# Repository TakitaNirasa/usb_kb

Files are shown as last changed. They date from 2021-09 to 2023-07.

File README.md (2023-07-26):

# Двухкнопочная клавиатура

[Проект печатной платы](https://github.com/TakitaNirasa/usb_kb/tree/main/sch_pcb)

[3D модели](https://github.com/TakitaNirasa/usb_kb/tree/main/3d_models%26drawings)

[Код](https://github.com/TakitaNirasa/usb_kb/tree/main/code/usb_kb_103)

[Схема](https://github.com/TakitaNirasa/usb_kb/tree/main/sch_pcb/usb_kb.pdf)

Для сборки проекта:
1. Перейти в директорию code/usb_kb_103/Debug
2. Собрать проект командой make all (Для сборки требуются пакеты: make, stlink-tools, binutils-arm-none-eabi)
3. Подключить плату к программатору (см. схему) и запитать её по usb кабелю
4. Ввести команду ./load_stm32

Скрин 3d модели корпуса для красоты:  

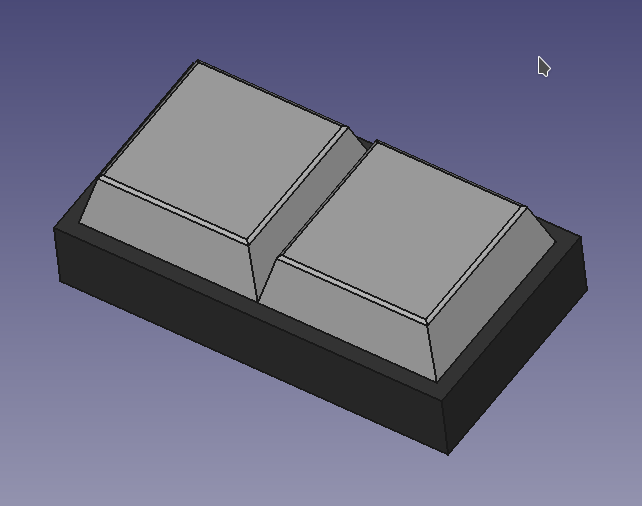
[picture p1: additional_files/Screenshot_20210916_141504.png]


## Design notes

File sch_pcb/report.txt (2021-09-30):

Информация: Обработка компонента "J1:/615DD6C5:Connector_PinHeader_2.54mm:PinHeader_1x04_P2.54mm_Vertical".
Информация: Обработка компонента "C14:/61573A60:Capacitor_SMD:C_0805_2012Metric_Pad1.15x1.40mm_HandSolder".
Информация: Обработка компонента "R14:/616A5D0F:Resistor_SMD:R_0603_1608Metric_Pad1.05x0.95mm_HandSolder".
Информация: Обработка компонента "C15:/61594438:Capacitor_SMD:C_0805_2012Metric_Pad1.15x1.40mm_HandSolder".
Информация: Обработка компонента "R13:/615C8D27:Resistor_SMD:R_0603_1608Metric_Pad1.05x0.95mm_HandSolder".
Информация: Обработка компонента "D1:/615BE243:Diode_SMD:D_SMA".
Информация: Обработка компонента "R12:/61584F00:Resistor_SMD:R_0603_1608Metric_Pad1.05x0.95mm_HandSolder".
Информация: Обработка компонента "D2:/6157EF82:Diode_SMD:D_0805_2012Metric_Pad1.15x1.40mm_HandSolder".
Информация: Обработка компонента "R11:/61567374:Resistor_SMD:R_0603_1608Metric_Pad1.05x0.95mm_HandSolder".
Информация: Обработка компонента "D3:/615BC87B:Diode_SMD:D_0805_2012Metric_Pad1.15x1.40mm_HandSolder".
Информация: Обработка компонента "R10:/61563424:Resistor_SMD:R_0603_1608Metric_Pad1.05x0.95mm_HandSolder".
Информация: Обработка компонента "D4:/615B3C03:Diode_SMD:D_0805_2012Metric_Pad1.15x1.40mm_HandSolder".
Информация: Обработка компонента "R9:/615BC881:Resistor_SMD:R_0603_1608Metric_Pad1.05x0.95mm_HandSolder".
Информация: Обработка компонента "R15:/616A4701:Resistor_SMD:R_0603_1608Metric_Pad1.05x0.95mm_HandSolder".
Информация: Обработка компонента "R8:/615B3C09:Resistor_SMD:R_0603_1608Metric_Pad1.05x0.95mm_HandSolder".
Информация: Обработка компонента "JP1:/615515A1:Jumper:SolderJumper-2_P1.3mm_Open_TrianglePad1.0x1.5mm".
Информация: Обработка компонента "R7:/615819F2:Resistor_SMD:R_0603_1608Metric_Pad1.05x0.95mm_HandSolder".
Информация: Обработка компонента "JP2:/61571C30:Jumper:SolderJumper-2_P1.3mm_Open_TrianglePad1.0x1.5mm".
Информация: Обработка компонента "R6:/6176BF06:Resistor_SMD:R_0603_1608Metric_Pad1.05x0.95mm_HandSolder".
Информация: Обработка компонента "P1:/6152BA8E:Connector_USB:USB_C_Receptacle_HRO_TYPE-C-31-M-12".
Информация: Обработка компонента "R5:/61687768:Resistor_SMD:R_0603_1608Metric_Pad1.05x0.95mm_HandSolder".
Информация: Обработка компонента "R1:/6155C064:Resistor_SMD:R_0603_1608Metric_Pad1.05x0.95mm_HandSolder".
Информация: Обработка компонента "R4:/615A1C71:Resistor_SMD:R_0603_1608Metric_Pad1.05x0.95mm_HandSolder".
Информация: Обработка компонента "R2:/6155F9D5:Resistor_SMD:R_0603_1608Metric_Pad1.05x0.95mm_HandSolder".
Информация: Обработка компонента "R3:/6163586F:Resistor_SMD:R_0603_1608Metric_Pad1.05x0.95mm_HandSolder".
Информация: Обработка компонента "C13:/616EB914:Capacitor_SMD:C_0805_2012Metric_Pad1.15x1.40mm_HandSolder".
Информация: Обработка компонента "C1:/6159B622:Capacitor_SMD:C_0805_2012Metric_Pad1.15x1.40mm_HandSolder".
Информация: Обработка компонента "C2:/61570A54:Capacitor_SMD:C_0805_2012Metric_Pad1.15x1.40mm_HandSolder".
Информация: Обработка компонента "X1:/615A0FA7:Crystal:Crystal_HC49-4H_Vertical".
Информация: Обработка компонента "C3:/615A45ED:Capacitor_SMD:C_0805_2012Metric_Pad1.15x1.40mm_HandSolder".
Информация: Обработка компонента "C4:/615A45E7:Capacitor_SMD:C_0805_2012Metric_Pad1.15x1.40mm_HandSolder".
Информация: Обработка компонента "U3:/615B256A:Package_TO_SOT_SMD:SOT-223-3_TabPin2".
Информация: Обработка компонента "C5:/61610E10:Capacitor_SMD:C_0805_2012Metric_Pad1.15x1.40mm_HandSolder".
Информация: Обработка компонента "C6:/61612EA3:Capacitor_SMD:C_0805_2012Metric_Pad1.15x1.40mm_HandSolder".
Информация: Обработка компонента "U2:/61609EAF:Package_TO_SOT_SMD:SOT-23-6".
Информация: Обработка компонента "C7:/61613FDA:Capacitor_SMD:C_0805_2012Metric_Pad1.15x1.40mm_HandSolder".
Информация: Обработка компонента "C8:/616148F3:Capacitor_SMD:C_0805_2012Metric_Pad1.15x1.40mm_HandSolder".
Информация: Обработка компонента "U1:/6153426E:Package_QFP:LQFP-48_7x7mm_P0.5mm".
Информация: Обработка компонента "C9:/615BF44D:Capacitor_SMD:C_0805_2012Metric_Pad1.15x1.40mm_HandSolder".
Информация: Обработка компонента "C10:/615BE780:Capacitor_SMD:C_0805_2012Metric_Pad1.15x1.40mm_HandSolder".
Информация: Обработка компонента "SW2:/615AD94E:Button_Switch_Keyboard:SW_Cherry_MX_1.00u_PCB".
Информация: Обработка компонента "C11:/61631C3A:Capacitor_SMD:C_0805_2012Metric_Pad1.15x1.40mm_HandSolder".
Информация: Обработка компонента "C12:/616EB91A:Capacitor_SMD:C_0805_2012Metric_Pad1.15x1.40mm_HandSolder".
Информация: Обработка компонента "SW1:/6155A06F:Button_Switch_Keyboard:SW_Cherry_MX_1.00u_PCB".
Добавлено U1 (посад.место "Package_QFP:LQFP-48_7x7mm_P0.5mm").
Добавлено SW2 (посад.место "Button_Switch_Keyboard:SW_Cherry_MX_1.00u_PCB").
Добавлено U2 (посад.место "Package_TO_SOT_SMD:SOT-23-6").
Добавлено U3 (посад.место "Package_TO_SOT_SMD:SOT-223-3_TabPin2").
Добавлено SW1 (посад.место "Button_Switch_Keyboard:SW_Cherry_MX_1.00u_PCB").
Добавлено X1 (посад.место "Crystal:Crystal_HC49-4H_Vertical").
Добавлено P1 (посад.место "Connector_USB:USB_C_Receptacle_HRO_TYPE-C-31-M-12").
Добавлено JP2 (посад.место "Jumper:SolderJumper-2_P1.3mm_Open_TrianglePad1.0x1.5mm").
Добавлено D1 (посад.место "Diode_SMD:D_SMA").
Добавлено JP1 (посад.место "Jumper:SolderJumper-2_P1.3mm_Open_TrianglePad1.0x1.5mm").
Добавлено J1 (посад.место "Connector_PinHeader_2.54mm:PinHeader_1x04_P2.54mm_Vertical").
Добавлено D2 (посад.место "Diode_SMD:D_0805_2012Metric_Pad1.15x1.40mm_HandSolder").
Добавлено D4 (посад.место "Diode_SMD:D_0805_2012Metric_Pad1.15x1.40mm_HandSolder").
Добавлено D3 (посад.место "Diode_SMD:D_0805_2012Metric_Pad1.15x1.40mm_HandSolder").
Ошибка: Не удалось добавить C7 (посад.место "Capacitor_SMD:C_0805_2012Metric_Pad1.15x1.40mm_HandSolder" не найдено).
Ошибка: Не удалось добавить C13 (посад.место "Capacitor_SMD:C_0805_2012Metric_Pad1.15x1.40mm_HandSolder" не найдено).
Ошибка: Не удалось добавить R15 (посад.место "Resistor_SMD:R_0603_1608Metric_Pad1.05x0.95mm_HandSolder" не найдено).
Ошибка: Не удалось добавить C12 (посад.место "Capacitor_SMD:C_0805_2012Metric_Pad1.15x1.40mm_HandSolder" не найдено).
Ошибка: Не удалось добавить C11 (посад.место "Capacitor_SMD:C_0805_2012Metric_Pad1.15x1.40mm_HandSolder" не найдено).
Ошибка: Не удалось добавить C10 (посад.место "Capacitor_SMD:C_0805_2012Metric_Pad1.15x1.40mm_HandSolder" не найдено).
Ошибка: Не удалось добавить C9 (посад.место "Capacitor_SMD:C_0805_2012Metric_Pad1.15x1.40mm_HandSolder" не найдено).
Ошибка: Не удалось добавить C8 (посад.место "Capacitor_SMD:C_0805_2012Metric_Pad1.15x1.40mm_HandSolder" не найдено).
Ошибка: Не удалось добавить R12 (посад.место "Resistor_SMD:R_0603_1608Metric_Pad1.05x0.95mm_HandSolder" не найдено).
Ошибка: Не удалось добавить C6 (посад.место "Capacitor_SMD:C_0805_2012Metric_Pad1.15x1.40mm_HandSolder" не найдено).
Ошибка: Не удалось добавить C5 (посад.место "Capacitor_SMD:C_0805_2012Metric_Pad1.15x1.40mm_HandSolder" не найдено).
Ошибка: Не удалось добавить C4 (посад.место "Capacitor_SMD:C_0805_2012Metric_Pad1.15x1.40mm_HandSolder" не найдено).
Ошибка: Не удалось добавить C3 (посад.место "Capacitor_SMD:C_0805_2012Metric_Pad1.15x1.40mm_HandSolder" не найдено).
Ошибка: Не удалось добавить C2 (посад.место "Capacitor_SMD:C_0805_2012Metric_Pad1.15x1.40mm_HandSolder" не найдено).
Ошибка: Не удалось добавить C1 (посад.место "Capacitor_SMD:C_0805_2012Metric_Pad1.15x1.40mm_HandSolder" не найдено).
Ошибка: Не удалось добавить R14 (посад.место "Resistor_SMD:R_0603_1608Metric_Pad1.05x0.95mm_HandSolder" не найдено).
Ошибка: Не удалось добавить C14 (посад.место "Capacitor_SMD:C_0805_2012Metric_Pad1.15x1.40mm_HandSolder" не найдено).
Ошибка: Не удалось добавить R13 (посад.место "Resistor_SMD:R_0603_1608Metric_Pad1.05x0.95mm_HandSolder" не найдено).
Ошибка: Не удалось добавить C15 (посад.место "Capacitor_SMD:C_0805_2012Metric_Pad1.15x1.40mm_HandSolder" не найдено).
Ошибка: Не удалось добавить R2 (посад.место "Resistor_SMD:R_0603_1608Metric_Pad1.05x0.95mm_HandSolder" не найдено).
Ошибка: Не удалось добавить R11 (посад.место "Resistor_SMD:R_0603_1608Metric_Pad1.05x0.95mm_HandSolder" не найдено).
Ошибка: Не удалось добавить R10 (посад.место "Resistor_SMD:R_0603_1608Metric_Pad1.05x0.95mm_HandSolder" не найдено).
Ошибка: Не удалось добавить R9 (посад.место "Resistor_SMD:R_0603_1608Metric_Pad1.05x0.95mm_HandSolder" не найдено).
Ошибка: Не удалось добавить R8 (посад.место "Resistor_SMD:R_0603_1608Metric_Pad1.05x0.95mm_HandSolder" не найдено).
Ошибка: Не удалось добавить R7 (посад.место "Resistor_SMD:R_0603_1608Metric_Pad1.05x0.95mm_HandSolder" не найдено).
Ошибка: Не удалось добавить R6 (посад.место "Resistor_SMD:R_0603_1608Metric_Pad1.05x0.95mm_HandSolder" не найдено).
Ошибка: Не удалось добавить R5 (посад.место "Resistor_SMD:R_0603_1608Metric_Pad1.05x0.95mm_HandSolder" не найдено).
Ошибка: Не удалось добавить R4 (посад.место "Resistor_SMD:R_0603_1608Metric_Pad1.05x0.95mm_HandSolder" не найдено).
Ошибка: Не удалось добавить R1 (посад.место "Resistor_SMD:R_0603_1608Metric_Pad1.05x0.95mm_HandSolder" не найдено).
Ошибка: Не удалось добавить R3 (посад.место "Resistor_SMD:R_0603_1608Metric_Pad1.05x0.95mm_HandSolder" не найдено).

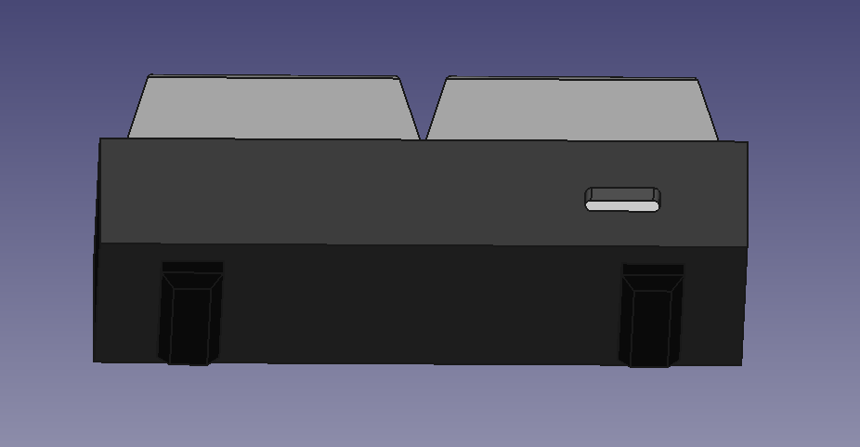
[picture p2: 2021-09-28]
additional_files/Screenshot_20210916_141544.png

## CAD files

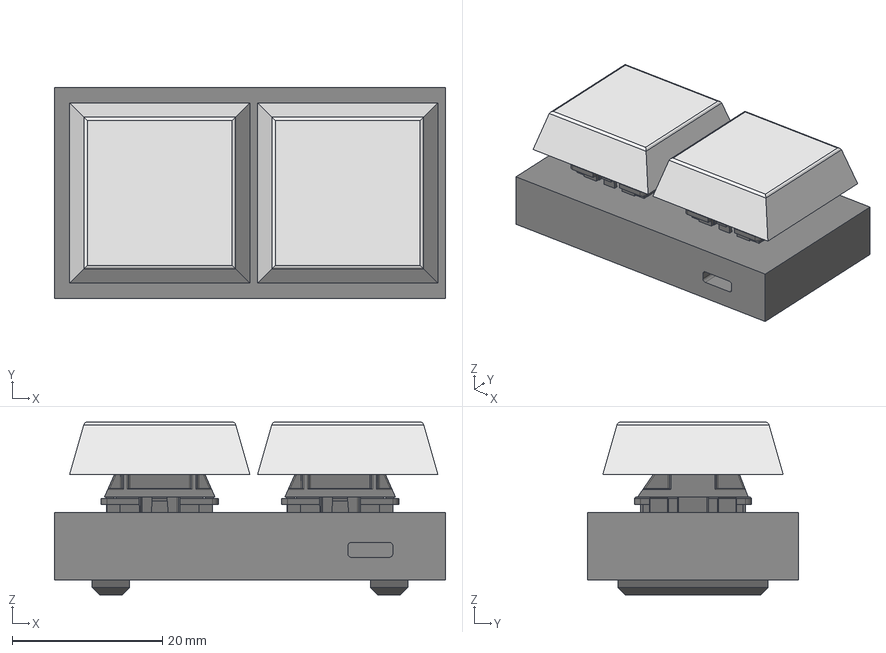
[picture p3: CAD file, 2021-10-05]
3d_models&drawings/kl1.0.FCStd
52.0 x 28.0 x 23.0 mm
BUTTON
BUTTON001
REZINKA
REZINKA001
KORP
SW_Cherry_MX_PCB_cp
SW_Cherry_MX_PCB_cp001

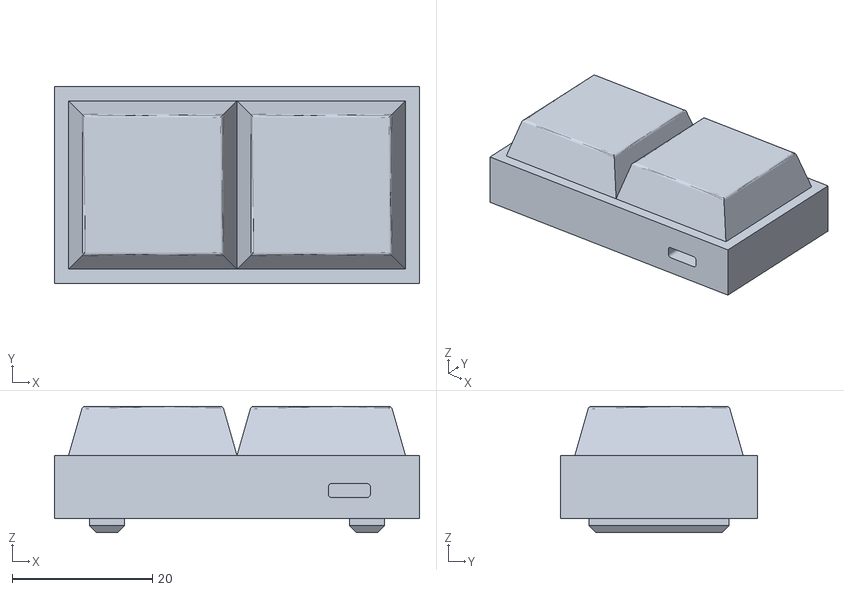
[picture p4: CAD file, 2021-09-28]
3d_models&drawings/usb_kb_sketch.stl
52.0 x 28.0 x 18.0

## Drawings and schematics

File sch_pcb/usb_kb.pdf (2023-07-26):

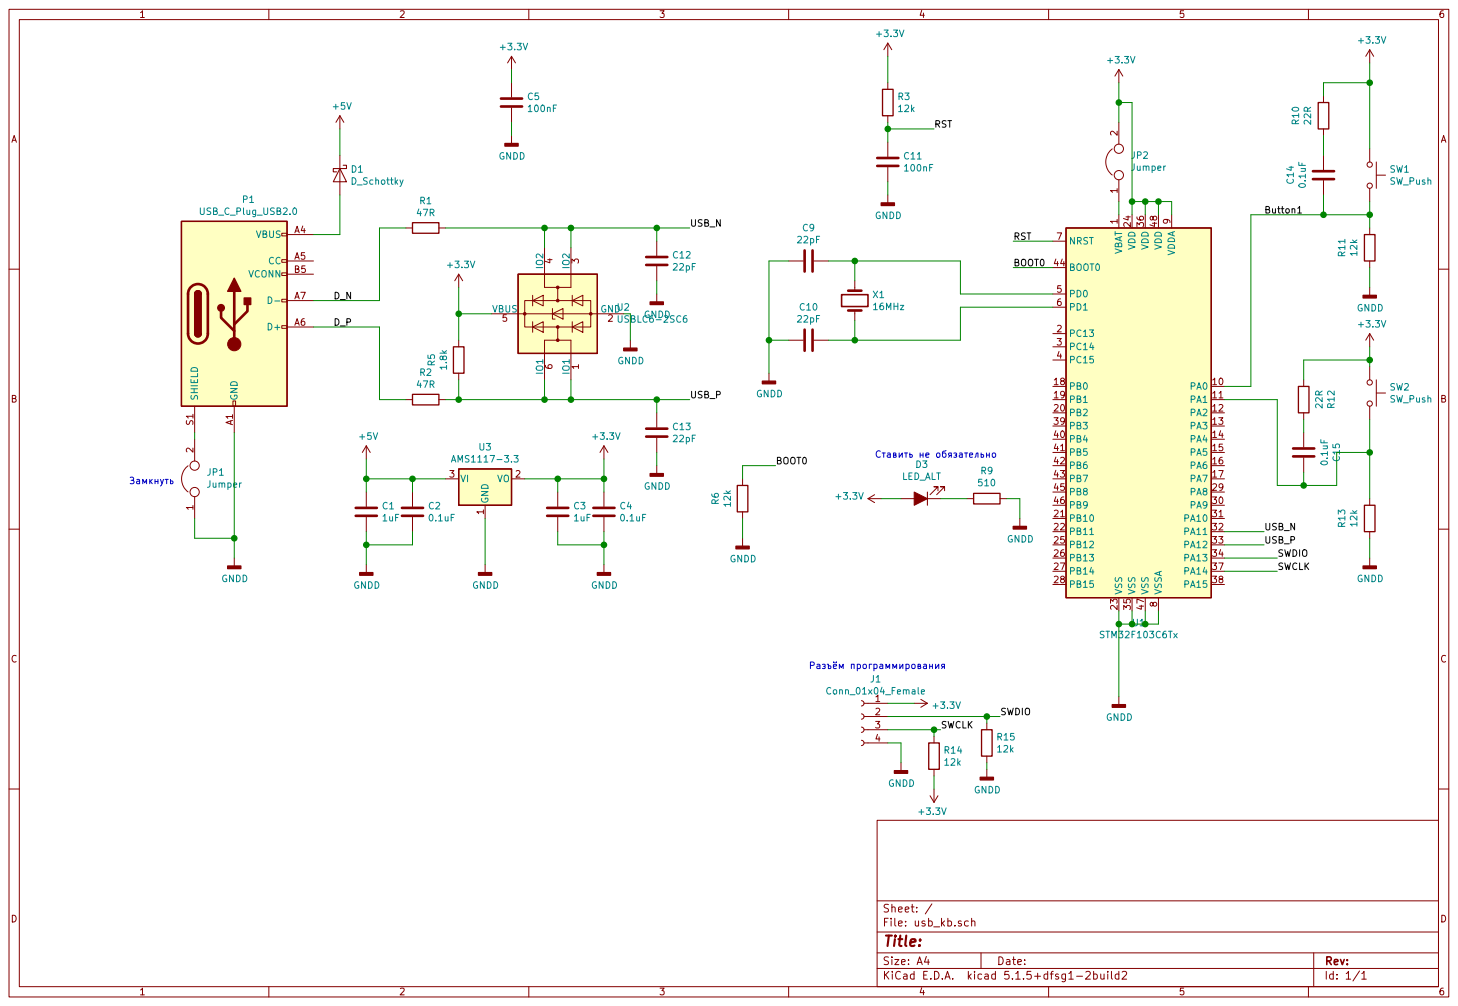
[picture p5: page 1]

1 VDD 24 VDD 36 VDD 48 VDDA

9 VSS 23 VSS 35 VSS 47 VSSA

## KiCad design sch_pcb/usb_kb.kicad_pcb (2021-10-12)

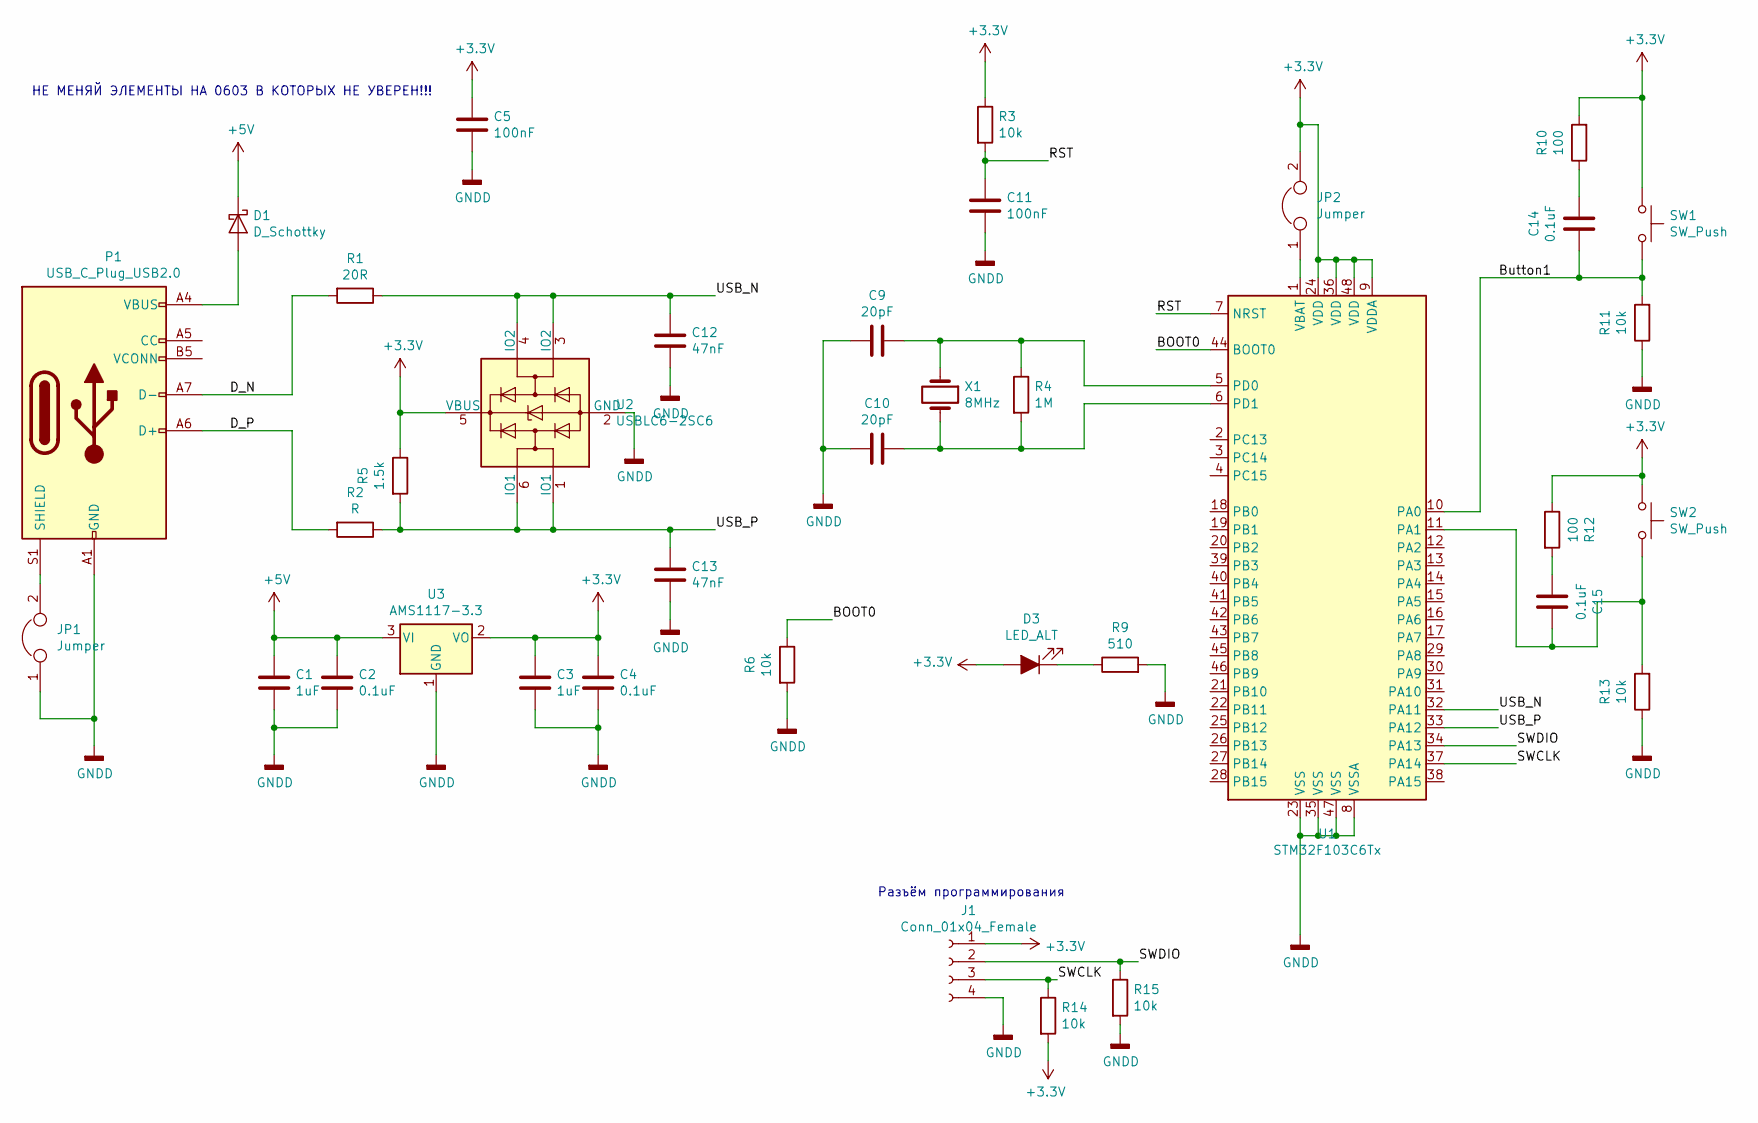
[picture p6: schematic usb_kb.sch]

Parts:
C1, C3: 1uF; C_0603_1608Metric_Pad1.05x0.95mm_HandSolder
C2, C4, C14, C15: 0.1uF; C_0603_1608Metric_Pad1.05x0.95mm_HandSolder
C5, C11: 100nF; C_0603_1608Metric_Pad1.05x0.95mm_HandSolder
C9, C10: 20pF; C_0603_1608Metric_Pad1.05x0.95mm_HandSolder
C12, C13: 47nF; C_0603_1608Metric_Pad1.05x0.95mm_HandSolder
D1: D_Schottky; D_MiniMELF_Handsoldering
D3: LED_ALT; D_0805_2012Metric_Pad1.15x1.40mm_HandSolder
J1: Conn_01x04_Female; PinHeader_1x04_P2.54mm_Vertical
JP1, JP2: Jumper; SolderJumper-2_P1.3mm_Open_TrianglePad1.0x1.5mm
P1: USB_C_Plug_USB2.0; USB_C_Receptacle_HRO_TYPE-C-31-M-12
R1: 20R; R_0603_1608Metric_Pad1.05x0.95mm_HandSolder
R2: R; R_0603_1608Metric_Pad1.05x0.95mm_HandSolder
R3, R6, R11, R13, R14, R15: 10k; R_0603_1608Metric_Pad1.05x0.95mm_HandSolder
R4: 1M; R_0603_1608Metric_Pad1.05x0.95mm_HandSolder
R5: 1.5k; R_0603_1608Metric_Pad1.05x0.95mm_HandSolder
R9: 510; R_0603_1608Metric_Pad1.05x0.95mm_HandSolder
R10, R12: 100; R_0603_1608Metric_Pad1.05x0.95mm_HandSolder
SW1, SW2: SW_Push; SW_Cherry_MX_1.00u_PCB
U1: STM32F103C6Tx; LQFP-48_7x7mm_P0.5mm
U2: USBLC6-2SC6; SOT-23-6
U3: AMS1117-3.3; SOT-223-3_TabPin2
X1: 8MHz; Crystal_HC49-4H_Vertical

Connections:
+3V3: C3.1, C4.1, C5.1, D3.2 (A), J1.1, JP2.2, R3.1, R5.1, R10.2, R12.1, R14.2, SW1.1, SW2.1, U1.9 (VDDA), U1.24 (VDD), U1.36 (VDD), U1.48 (VDD), U2.5 (VBUS), U3.2 (VO)
+5V: C1.1, C2.1, D1.1 (K), U3.3 (VI)
/BOOT0: R6.1, U1.44 (BOOT0)
/Button1: C14.2, R11.2, SW1.2, U1.10 (PA0)
/D_N: P1.A7 (D-), R1.2
/D_P: P1.A6 (D+), R2.2
/RST: C11.1, R3.2, U1.7 (NRST)
/SWCLK: J1.3, R14.1, U1.37 (PA14)
/SWDIO: J1.2, R15.1, U1.34 (PA13)
/USB_N: C12.1, R1.1, U1.32 (PA11), U2.3 (IO2), U2.4 (IO2)
/USB_P: C13.1, R2.1, R5.2, U1.33 (PA12), U2.1 (IO1), U2.6 (IO1)
GNDD: C1.2, C2.2, C3.2, C4.2, C5.2, C9.2, C10.2, C11.2, C12.2, C13.2, J1.4, JP1.1, P1.A1 (GND), P1.A12 (GND), P1.B1 (GND), P1.B12 (GND), R6.2, R9.2, R11.1, R13.1, R15.2, U1.8 (VSSA), U1.23 (VSS), U1.35 (VSS), U1.47 (VSS), U2.2 (GND), U3.1 (GND)
unnamed: C9.1, R4.1, U1.5 (PD0), X1.1
unnamed: C10.1, R4.2, U1.6 (PD1), X1.2
unnamed: C14.1, R10.1
unnamed: C15.1, R13.2, SW2.2, U1.11 (PA1)
unnamed: C15.2, R12.2
unnamed: D1.2 (A), P1.A4 (VBUS), P1.A9 (VBUS), P1.B4 (VBUS), P1.B9 (VBUS)
unnamed: D3.1 (K), R9.1
unnamed: JP1.2, P1.S1 (SHIELD)
unnamed: JP2.1, U1.1 (VBAT)

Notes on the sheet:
НЕ МЕНЯЙ ЭЛЕМЕНТЫ НА 0603 В КОТОРЫХ НЕ УВЕРЕН!!!
Разъём программирования

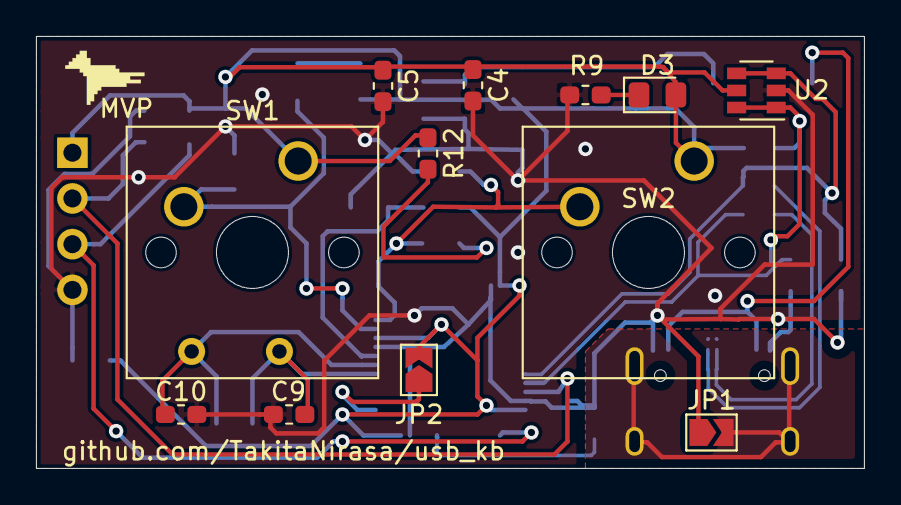
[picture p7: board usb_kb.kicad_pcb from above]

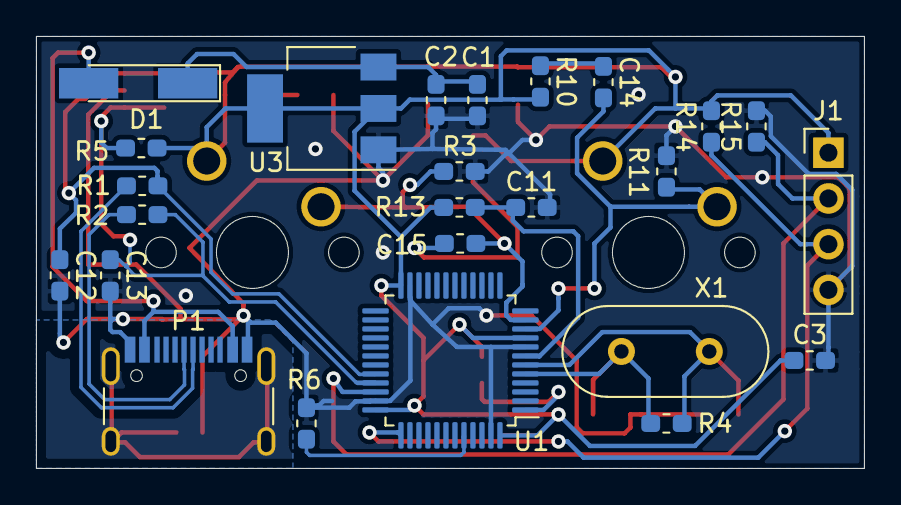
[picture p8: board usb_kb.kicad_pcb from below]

Board: 2 copper layers, 46.0 x 24.0 mm, 37 parts (25 on the bottom side), 21 nets.

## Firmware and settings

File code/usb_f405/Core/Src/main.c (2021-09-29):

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
/* Includes ------------------------------------------------------------------*/
#include "main.h"
#include "usb_device.h"
#include "usbd_hid.h"


/* USER CODE BEGIN PV */
extern USBD_HandleTypeDef hUsbDeviceFS;

typedef struct
{
	uint8_t MODIFIER;
	uint8_t RESERVED;
	uint8_t KEYCODE1;
	uint8_t KEYCODE2;
	uint8_t KEYCODE3;
	uint8_t KEYCODE4;
	uint8_t KEYCODE5;
	uint8_t KEYCODE6;
}subKeyBoard;

uint8_t keyBoardHIDsub[] = {0,0,0,0,0,0,0,0};
/* USER CODE END PV */
void send_word(uint8_t num, uint8_t ctrl)
{
	if (ctrl)
	{
	  keyBoardHIDsub[0]=0x01;  // To press shift key<br>
	}
	  keyBoardHIDsub[2]=num;  // Press  key
	  USBD_HID_SendReport(&hUsbDeviceFS,keyBoardHIDsub,sizeof(keyBoardHIDsub));
	  HAL_Delay(50); 		       // Press all key for 50 milliseconds
	  keyBoardHIDsub[0]=0x00;  // To unpress ctrl key<br>
	  keyBoardHIDsub[2]=0x00;  // unPress key
	  USBD_HID_SendReport(&hUsbDeviceFS,keyBoardHIDsub,sizeof(keyBoardHIDsub));
	  HAL_Delay(400); 	       // Repeat this task on every 1 second
}
void SystemClock_Config(void);
static void MX_GPIO_Init(void);
typedef enum pos_button_e
{
	  button_push,
	  button_free
}pos_button_t;
/**
  * @brief  The application entry point.
  * @retval int
  */
int main(void)
{
  /* MCU Configuration--------------------------------------------------------*/

  /* Reset of all peripherals, Initializes the Flash interface and the Systick. */
  HAL_Init();

  /* Configure the system clock */
  SystemClock_Config();

  /* Initialize all configured peripherals */
  MX_GPIO_Init();
  MX_USB_DEVICE_Init();
  pos_button_t button_position = HAL_GPIO_ReadPin(GPIOA, 0) ? button_push : button_free;
  uint8_t was_done_copy = 0;
  uint8_t counter;


  /* Infinite loop */
  /* USER CODE BEGIN WHILE */
  while (1)
  {
	  if (button_position == button_push && counter > 10)
	 	  counter = (GPIOA->IDR & 1) ? 255 : counter - 1;
	   else if (button_position == button_free && counter < 240)
	   	  counter = (GPIOA->IDR & 1) ? 0 : counter + 1;
	   else if (button_position == button_push && counter <= 10)
	   {
	 	  	  button_position = button_free;
	 	  	  counter = 0;
	 	  	  // Если уже нажали ctrl+c, то жмём ctrl+v
	 	  	  if (was_done_copy)
	 	  		  send_word(0x19, 1);
	 	  	  else
	 	  		  send_word(0x06, 1);
	 	  	  //меняем значение
	 	  	  was_done_copy ^= 1;

	   }
	   else if (button_position == button_free && counter >= 240)
	   {
	 	  	  button_position = button_push;
	 	  	  counter = 255;
	   }	       // Repeat this task on every 1 second
  }
  /* USER CODE END 3 */
}

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


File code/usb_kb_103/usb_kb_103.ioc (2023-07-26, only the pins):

Mcu.UserName=STM32F103C6Tx
PA0-WKUP.Signal=SYS_WKUP
PA1.Signal=GPIO_Input
PA11.Signal=USB_DM
PA12.Signal=USB_DP
PA13.Signal=SYS_JTMS-SWDIO
PA14.Signal=SYS_JTCK-SWCLK
PA3.Signal=GPIO_Input
PD0-OSC_IN.Signal=RCC_OSC_IN
PD1-OSC_OUT.Signal=RCC_OSC_OUT

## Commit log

2021-09-28 Added sources
    [usb_kb.kicad_pcb, usb_kb.sch]
2021-09-28 Scetches added
    [kl1.0.FCStd, usb_kb_sketch.stl]
2021-09-28 Добавлен тупой комментарий для примера коммита
2021-09-28 Андрей изменил схему, добавил стабилизатор
    [usb_kb.sch]
2021-09-28 Update main.c
    Показываю Андрею как коммитить
2021-09-29 добавлена кнопка на PA0 которая делает копипаст
2021-09-29 Андрей добавил питание, Никита доделал
    [usb_kb.kicad_pcb, usb_kb.sch]
2021-09-29 Добавлена кнопа и мелкие правки
    Добавлена кнопа и мелкие правки
    [usb_kb.sch]
2021-09-30 ошибка R11. Конечный вариант
    [usb_kb.kicad_pcb, usb_kb.sch]
2021-10-01 Новые посадочные места
    [usb_kb.kicad_pcb, usb_kb.sch]
2021-10-01 Исправил посадочное место USB
    [usb_kb.sch]
2021-10-05 Разработал схему
    [kl1.0.FCStd, usb_kb.kicad_pcb, usb_kb.sch]
2021-10-11 Переделал схему, добавил дифф пару
    [usb_kb.kicad_pcb, usb_kb.sch]
2021-10-11 Добавил герберы
    [usb_kb-B_Cu.gbl, usb_kb-B_Mask.gbs, usb_kb-B_Paste.gbp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]
2021-10-12 Поправил герберы
    [usb_kb-B_Cu.gbl, usb_kb-B_Mask.gbs, usb_kb-B_Paste.gbp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]
2023-07-26 Добавлен код для целевого контроллера
    [usb_kb_103.cfg]
2023-07-26 Добавлена схема
2023-07-26 Добавлена ссылка на схему в ридми

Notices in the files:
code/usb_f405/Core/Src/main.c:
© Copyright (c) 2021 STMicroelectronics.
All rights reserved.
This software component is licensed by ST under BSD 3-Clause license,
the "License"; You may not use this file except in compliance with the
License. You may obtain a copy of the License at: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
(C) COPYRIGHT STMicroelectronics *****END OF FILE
